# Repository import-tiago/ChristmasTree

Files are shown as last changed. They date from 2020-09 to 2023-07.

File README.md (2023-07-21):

# ChristmasTree

 

## PCB Preview
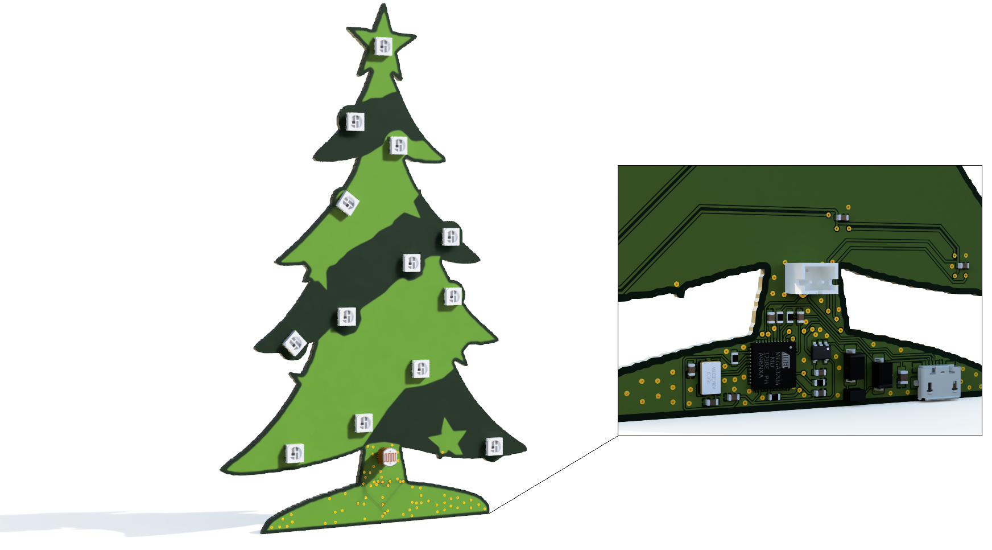
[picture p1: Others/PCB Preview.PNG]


## Schematic
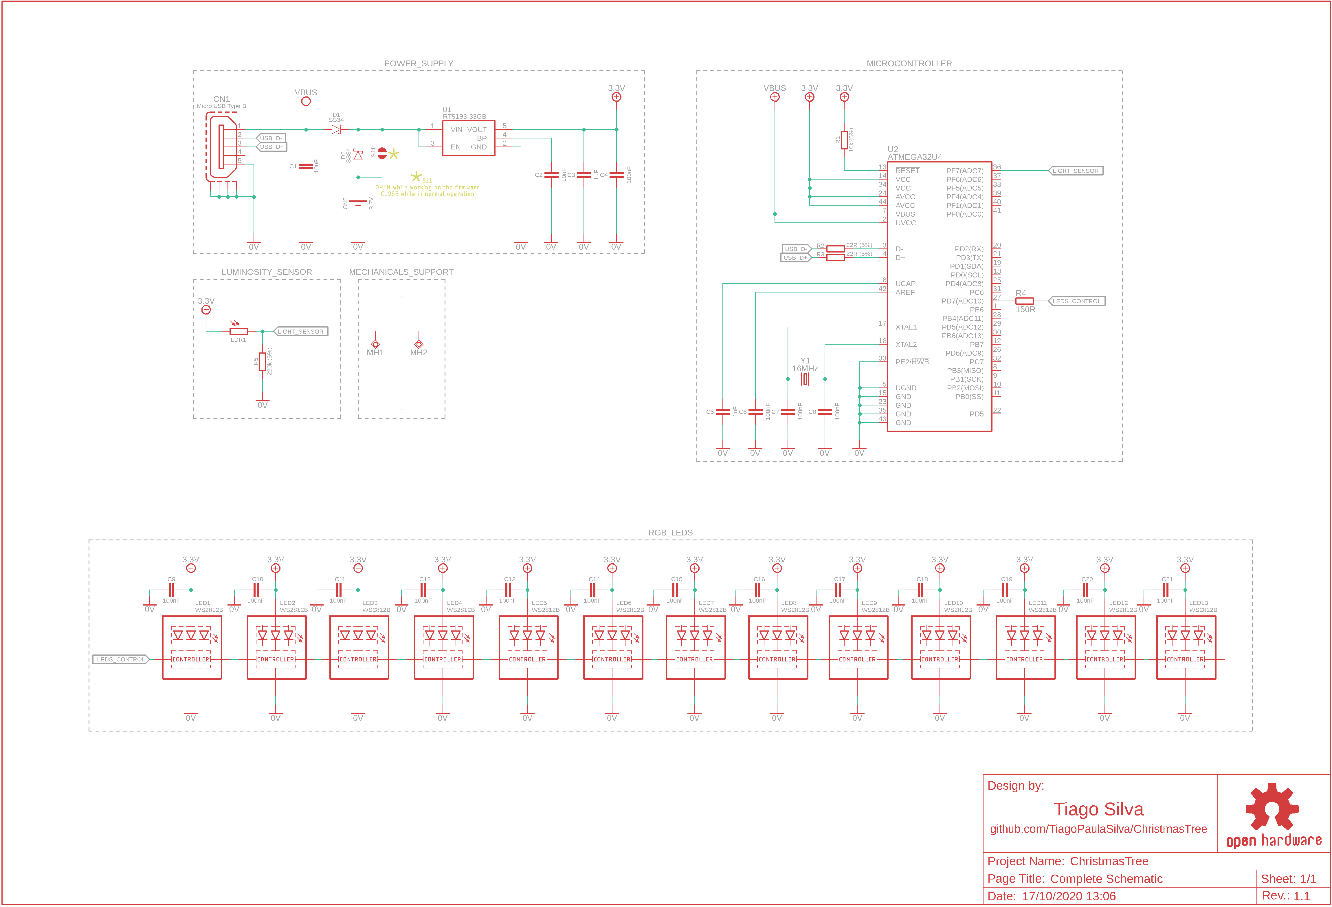
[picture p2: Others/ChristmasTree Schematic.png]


## Bill of Materials
| Qty | Parts | Description | Value | Package |
|--|--|--|--|--|
1|R1|SMD Resistor|10k ±5%|R0603
2|R2/R3|SMD Resistor|22R ±5%|R0603
1|R4|SMD Resistor|150R ±5%|R0603
1|R5|SMD Resistor|220k ±5%|R0603
1|C1|SMD Capacitor|1uF / 50V|C0805
1|C2|SMD Capacitor|10nF / 50V|C0603
2|C3/C5|SMD Capacitor|1uF / 50V|C0603
17|C4/C6~C21|SMD Capacitor|100nF / 50V|C0603
1|LDR1|PTH LDR|1 MΩ (Lux 0) / 10-20 KΩ (Lux 10)|5mm
1|Y1|SMD Crystal|8MHz|5.0mm x 3.2mm
1|U1|SMD Integrated Circuit|RT9193-33GB|SOT23-5
1|U2|SMD Integrated Circuit|ATMEGA32U4|QFN-44
2|D1/D2|SMD Diode|SS34|DO214AB
1|CN1|SMD Connector|MISB-SW-5B|Micro USB Type B
1|CN2|PTH Connector|JST-PH-2P|2-pin
13|LED1~LED13|SMD RGB LED|WS2812B|5050

### Contributing
0. Give this project a :star:
1. Create an issue and describe your idea.
2. [Fork it](https://github.com/import-tiago/ChristmasTree/fork).
3. Create your feature branch (`git checkout -b my-new-feature`).
4. Commit your changes (`git commit -a -m "Added feature title"`).
5. Publish the branch (`git push origin my-new-feature`).
6. Create a new pull request.
7. Done! :heavy_check_mark:

### License Information
<br /><span xmlns:dct="http://purl.org/dc/terms/" property="dct:title">ChristmasTree</span> by <a xmlns:cc="http://creativecommons.org/ns#" href="https://github.com/import-tiago" property="cc:attributionName" rel="cc:attributionURL">Tiago Silva</a> is licensed under a <a rel="license" href="http://creativecommons.org/licenses/by-sa/4.0/">Creative Commons Attribution-ShareAlike 4.0 International License</a>.<br />Permissions beyond the scope of this license may be available at <a xmlns:cc="http://creativecommons.org/ns#" href="https://twitter.com/import_tiago" rel="cc:morePermissions">tiagodepaulasilva@gmail.com</a>.

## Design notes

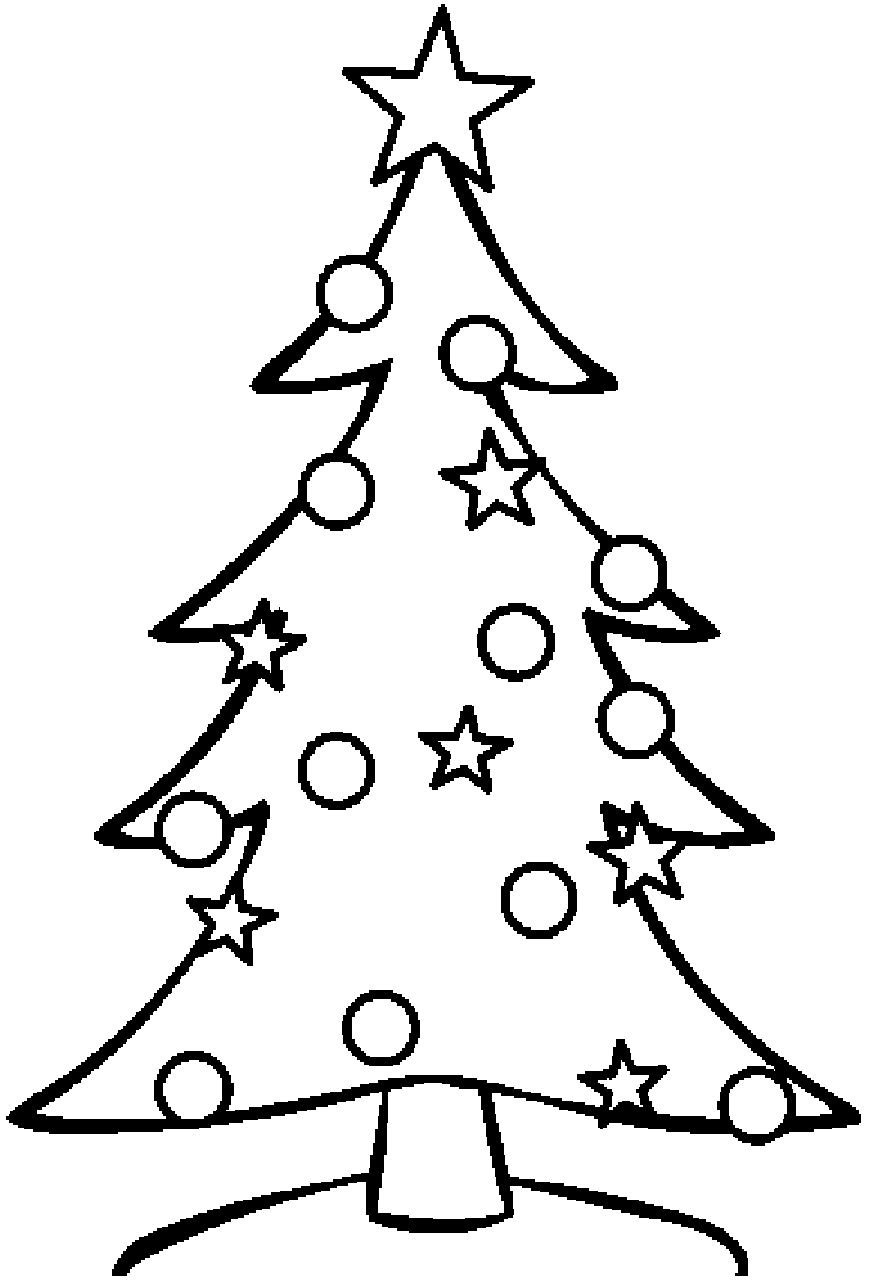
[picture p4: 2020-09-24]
Hardware/4. Others/ChristmasTree (Preview).bmp

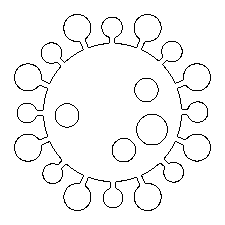
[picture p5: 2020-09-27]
Hardware/4. Others/Coronavirus.bmp

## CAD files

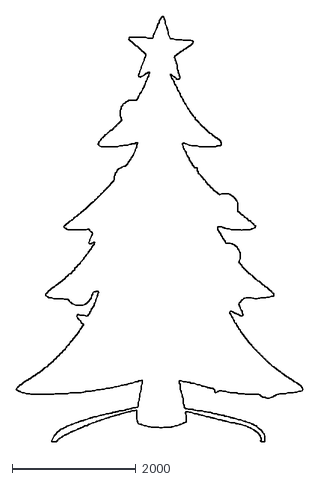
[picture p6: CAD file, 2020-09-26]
Hardware/4. Others/ChristmasTree (External Border).dxf
4616.3 x 6867.9

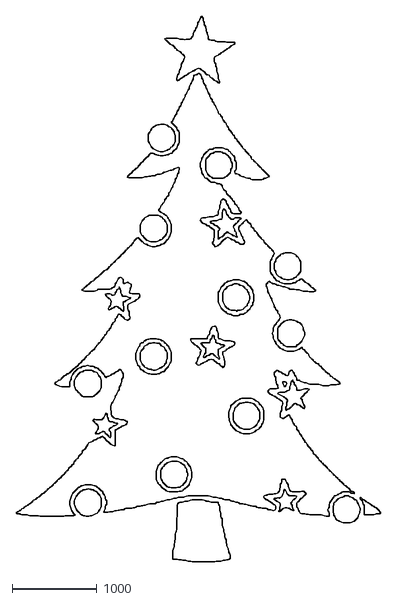
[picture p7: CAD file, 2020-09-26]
Hardware/4. Others/ChristmasTree (Internal Border).dxf
4292.5 x 6428.1

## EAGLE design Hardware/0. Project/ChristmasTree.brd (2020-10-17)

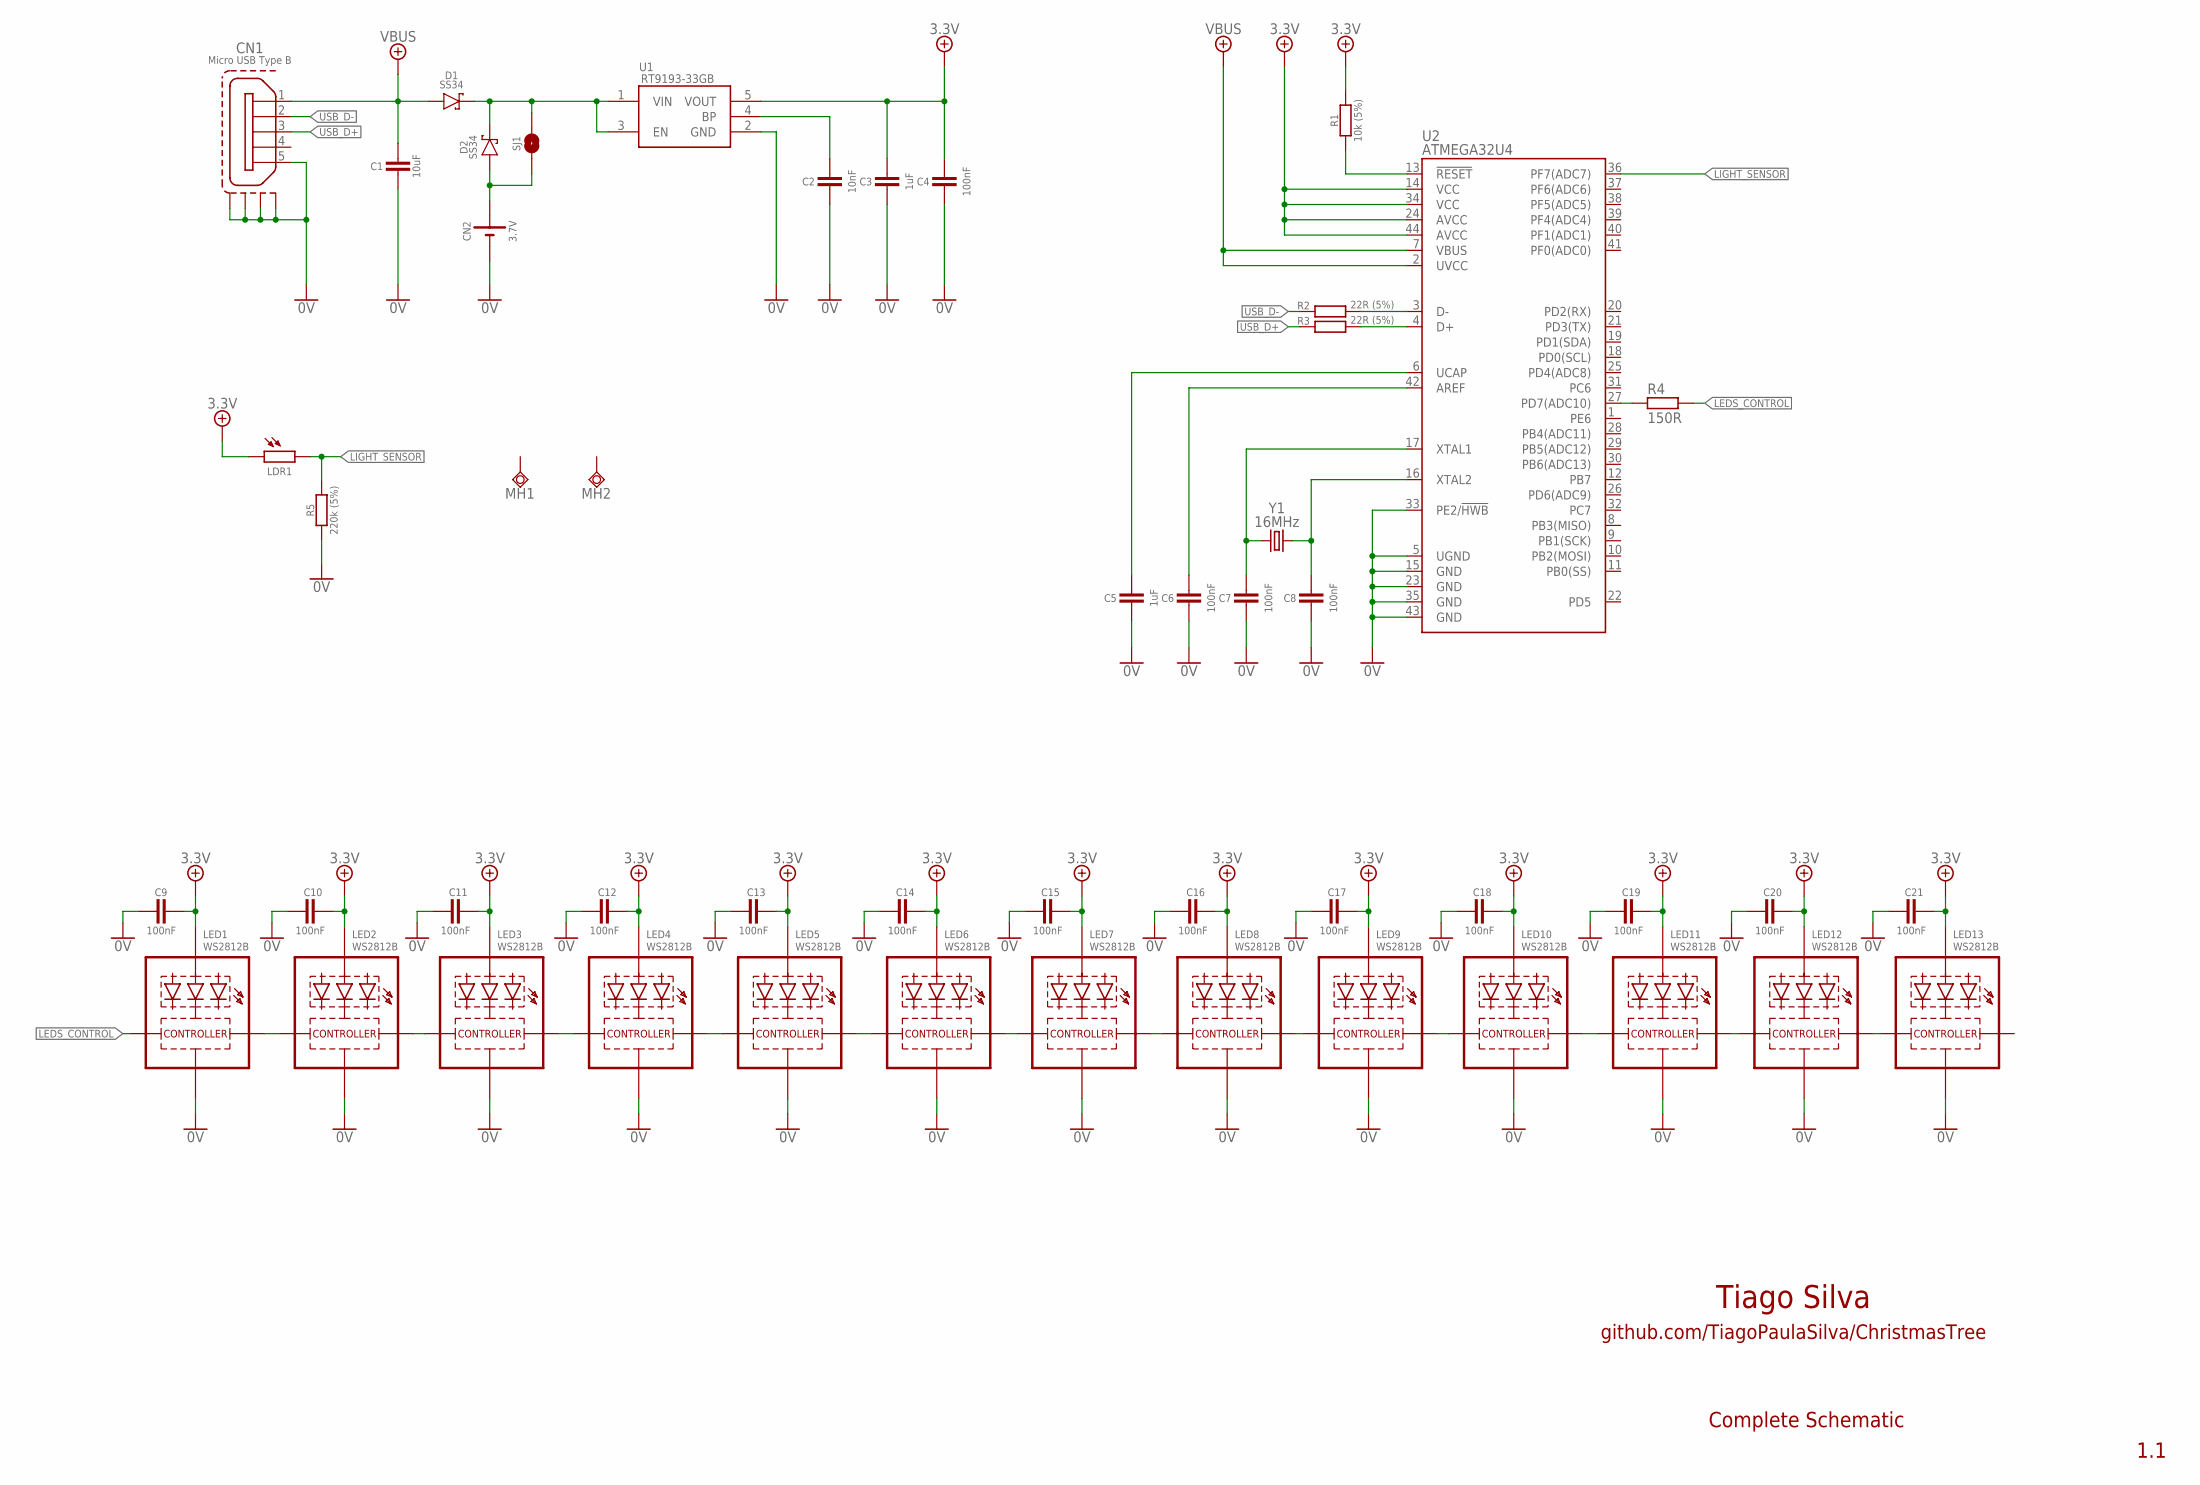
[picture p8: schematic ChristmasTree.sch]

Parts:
C1: 10uF; C0805
C2: 10nF; C0603
C3, C5: 1uF; C0603
C4, C6, C7, C8, C9, C10, C11, C12, C13, C14, C15, C16, C17, C18, C19, C20, C21: 100nF; C0603
CN1: Micro USB Type B; 10118193-0001LF
CN2: 3.7V; JST-PH2
D1, D2: SS34; DO214AB
LDR1: A1050_09; T0-46-A10XX
LED1, LED2, LED3, LED4, LED5, LED6, LED7, LED8, LED9, LED10, LED11, LED12, LED13: WS2812B; 5050
MH1, MH2: TPSQTP20R; TP20R
R1: 10k (5%); R0603
R2, R3: 22R (5%); R0603
R4: 150R; R0603
R5: 220k (5%); R0603
SJ1: SJ
U1: RT9193-33GB; SOT94P279X129-5N
U2: ATMEGA32U4; TESTING_QFN-44
Y1: 16MHz; 5.0X3.2_KX-9A

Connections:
0V: C1.2, C2.2, C3.2, C4.2, C5.2, C6.2, C7.2, C8.2, C9.2, C10.2, C11.2, C12.2, C13.2, C14.2, C15.2, C16.2, C17.2, C18.2, C19.2, C20.2, C21.2, CN1.5, CN1.MP1 (S1), CN1.MP2 (S2), CN1.MP3 (S3), CN1.MP4 (S4), CN2.2 (-), LED1.3-GND (GND), LED2.3-GND (GND), LED3.3-GND (GND), LED4.3-GND (GND), LED5.3-GND (GND), LED6.3-GND (GND), LED7.3-GND (GND), LED8.3-GND (GND), LED9.3-GND (GND), LED10.3-GND (GND), LED11.3-GND (GND), LED12.3-GND (GND), LED13.3-GND (GND), R5.1, U1.2 (GND), U2.5 (UGND), U2.15 (GND), U2.23 (GND), U2.33 (PE2/!HWB), U2.35 (GND), U2.43 (GND)
3.3V: C3.1, C4.1, C9.1, C10.1, C11.1, C12.1, C13.1, C14.1, C15.1, C16.1, C17.1, C18.1, C19.1, C20.1, C21.1, LDR1.1, LED1.1-VDD (VDD), LED2.1-VDD (VDD), LED3.1-VDD (VDD), LED4.1-VDD (VDD), LED5.1-VDD (VDD), LED6.1-VDD (VDD), LED7.1-VDD (VDD), LED8.1-VDD (VDD), LED9.1-VDD (VDD), LED10.1-VDD (VDD), LED11.1-VDD (VDD), LED12.1-VDD (VDD), LED13.1-VDD (VDD), R1.2, U1.5 (VOUT), U2.14 (VCC), U2.24 (AVCC), U2.34 (VCC), U2.44 (AVCC)
LEDS_CONTROL: LED1.4-DIN (DI), R4.2
LIGHT_SENSOR: LDR1.2, R5.2, U2.36 (PF7(ADC7))
unnamed: LED3.2-DOUT (DO), LED4.4-DIN (DI)
unnamed: LED1.2-DOUT (DO), LED2.4-DIN (DI)
unnamed: R4.1, U2.27 (PD7(ADC10))
unnamed: LED2.2-DOUT (DO), LED3.4-DIN (DI)
unnamed: LED5.2-DOUT (DO), LED6.4-DIN (DI)
unnamed: LED8.2-DOUT (DO), LED9.4-DIN (DI)
unnamed: LED6.2-DOUT (DO), LED7.4-DIN (DI)
unnamed: LED10.2-DOUT (DO), LED11.4-DIN (DI)
unnamed: LED9.2-DOUT (DO), LED10.4-DIN (DI)
unnamed: LED12.2-DOUT (DO), LED13.4-DIN (DI)
unnamed: LED4.2-DOUT (DO), LED5.4-DIN (DI)
unnamed: R3.2, U2.4 (D+)
unnamed: LED11.2-DOUT (DO), LED12.4-DIN (DI)
unnamed: LED7.2-DOUT (DO), LED8.4-DIN (DI)
unnamed: C7.1, U2.17 (XTAL1), Y1.1
unnamed: C8.1, U2.16 (XTAL2), Y1.3 (2)
unnamed: C5.1, U2.6 (UCAP)
unnamed: C6.1, U2.42 (AREF)
unnamed: CN2.1 (+), D2.A, SJ1.1
unnamed: R2.2, U2.3 (D-)
unnamed: C2.1, U1.4 (BP)
RESET: R1.1, U2.13 (!RESET)
USB_D+: CN1.3, R3.1
USB_D-: CN1.2, R2.1
VBAT: D1.C (K), D2.C (K), SJ1.2, U1.1 (VIN), U1.3 (EN)
VBUS: C1.1, CN1.1, D1.A, U2.2 (UVCC), U2.7 (VBUS)

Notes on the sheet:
Tiago Silva
github.com/TiagoPaulaSilva/ChristmasTree
1.1
Complete Schematic

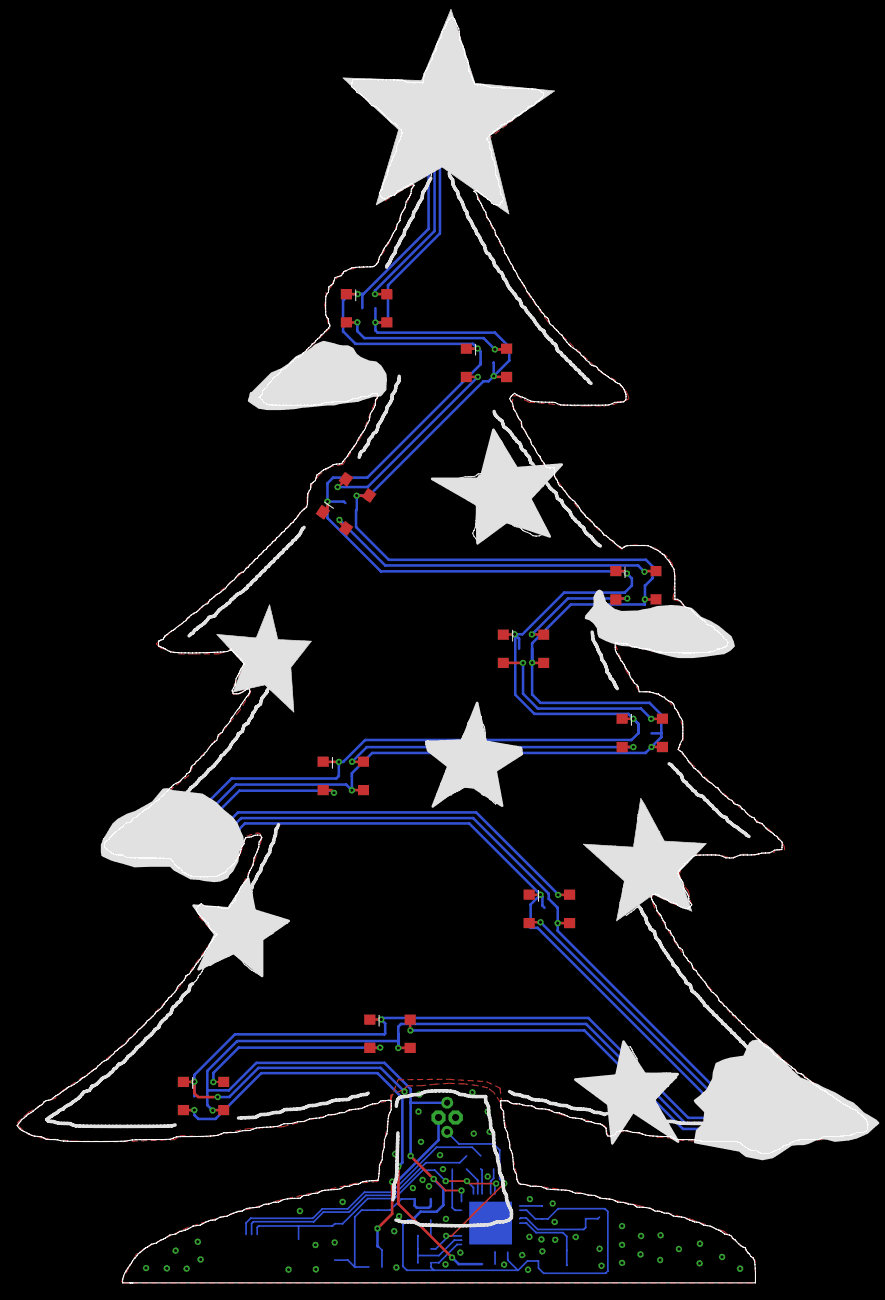
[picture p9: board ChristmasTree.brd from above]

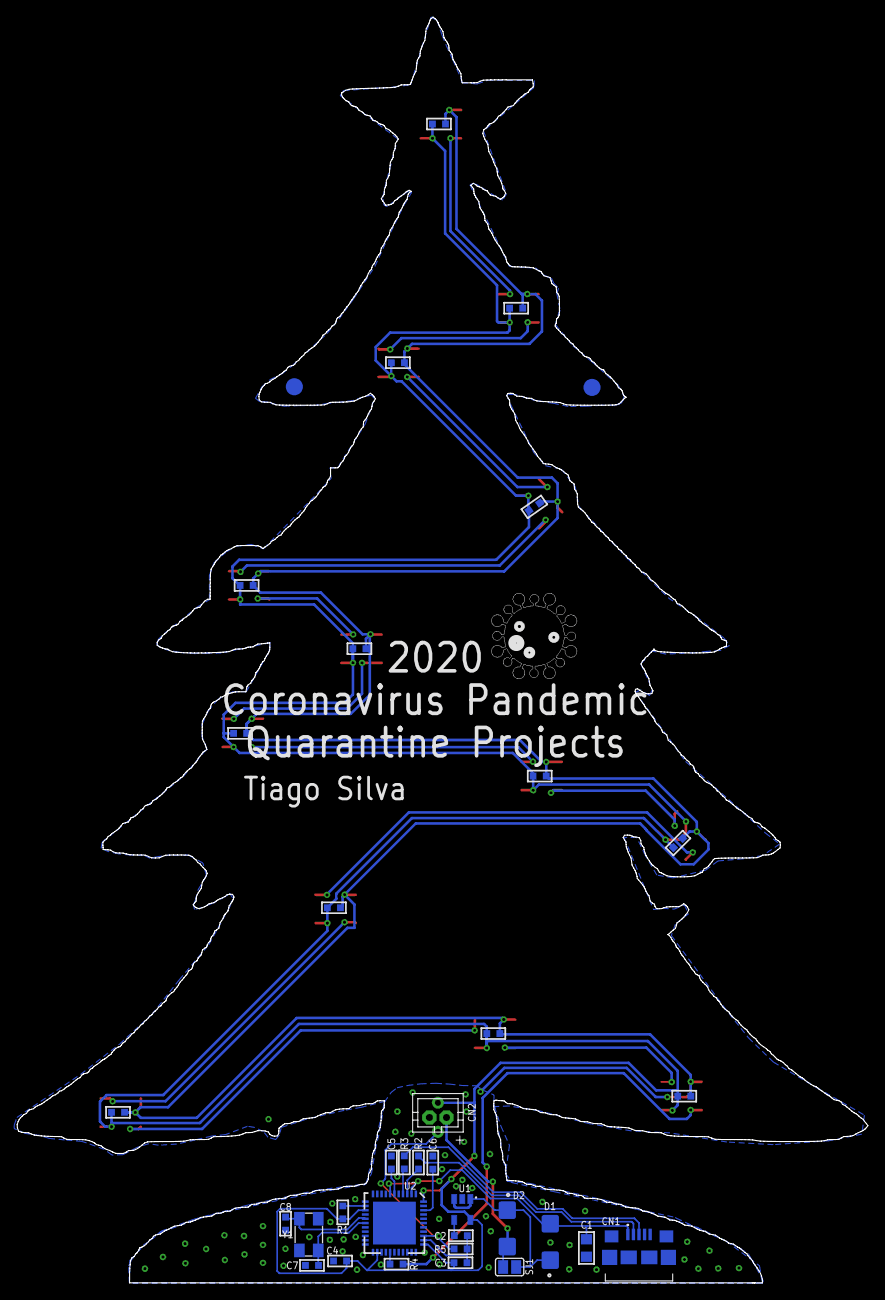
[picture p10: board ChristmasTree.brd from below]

Board: 2 copper layers, 99.3 x 147.7 mm, 50 parts (37 on the bottom side), 30 nets.

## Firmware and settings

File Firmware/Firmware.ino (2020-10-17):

/* sinelon

   By: Mark Kriegsman

   Modified by: Andrew Tuline

   Adapted by: Tiago Silva (2020)

   This uses the built in beat in FastLED to move a dot back and forth. In this case, it uses two beats added together for more randomness.

*/

#include "FastLED.h"                                          // FastLED library. Preferably the latest copy of FastLED 2.1.

#if FASTLED_VERSION < 3001000
#error "Requires FastLED 3.1 or later; check github for latest code."
#endif

#define NUM_LEDS 13
#define DATA_PIN 6

#define LDR_PIN A0
#define LIGHT_LEVEL 750

CRGB leds[NUM_LEDS];

// Global variables can be changed on the fly.
uint8_t max_bright = 64;                                      // Overall brightness definition. It can be changed on the fly.

CRGBPalette16 currentPalette;
CRGBPalette16 targetPalette;
TBlendType    currentBlending;                                // NOBLEND or LINEARBLEND

// Define variables used by the sequences.
uint8_t thisbeat =  23;                                       // Beats per minute for first part of dot.
uint8_t thatbeat =  28;                                       // Combined the above with this one.
uint8_t thisfade =   32;                                       // How quickly does it fade? Lower = slower fade rate.
uint8_t  thissat = 255;                                       // The saturation, where 255 = brilliant colours.
uint8_t  thisbri = 255;                                       // Brightness of a sequence.
int        myhue =   0;

int    thisdelay = 50;



void setup() {
  
  Serial.begin(9600);
  
  pinMode(LDR_PIN, INPUT);

  FastLED.addLeds<WS2812B, DATA_PIN, GRB>(leds, NUM_LEDS);

  currentBlending = LINEARBLEND;

  FastLED.setBrightness(max_bright);
  FastLED.setMaxPowerInVoltsAndMilliamps(3, 500);               // FastLED Power management set at 5V, 500mA.

} // setup()



void loop () {

  long Current_Light_Level = 0;
  for (int i = 0; i < 100; i++) {
    Current_Light_Level += analogRead(LDR_PIN);
  }
  Current_Light_Level /= 100;  
  Serial.println(Current_Light_Level);

  thisbri = Current_Light_Level / 4;

  if (thisbri < 30)
    thisbri = 30;

  //Serial.println(thisbri);
  if (Current_Light_Level < LIGHT_LEVEL) {

    EVERY_N_MILLISECONDS(50) {
      uint8_t maxChanges = 35;
      nblendPaletteTowardPalette(currentPalette, targetPalette, maxChanges);   // AWESOME palette blending capability.
    }

    EVERY_N_SECONDS(5) {                                        // Change the target palette to a random one every 5 seconds.
      static uint8_t baseC = random8();                         // You can use this as a baseline colour if you want similar hues in the next line.
      targetPalette = CRGBPalette16(CHSV(random8(), 255, random8(128, 255)), CHSV(random8(), 255, random8(128, 255)), CHSV(random8(), 192, random8(128, 255)), CHSV(random8(), 255, random8(128, 255)));
    }

    EVERY_N_MILLISECONDS(thisdelay) {                           // FastLED based non-blocking delay to update/display the sequence.
      sinelon();                                                // Call our sequence.
    }

    FastLED.show();
  }
  else {
    for (int i = 0; i < NUM_LEDS; i++) {
      leds[i] = CRGB::Black;
      FastLED.show();
    }
  }
}

void sinelon() {                                              // a colored dot sweeping back and forth, with fading trails

  fadeToBlackBy( leds, NUM_LEDS, thisfade);
  int pos1 = beatsin16(thisbeat, 0, NUM_LEDS);
  int pos2 = beatsin16(thatbeat, 0, NUM_LEDS);
  int pos = (pos1 + pos2) / 2;

  if (pos > (NUM_LEDS - 1))
    pos = 0;

  leds[pos] += ColorFromPalette(currentPalette, myhue++, thisbri, currentBlending);
}

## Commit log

2020-09-25 PCB 100mm
    [ChristmasTree.brd, ChristmasTree.sch]
2020-09-27 PCB 1.0 done
    [ChristmasTree (External Border).dxf, ChristmasTree (Internal Border).dxf, ChristmasTree.brd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]
2020-10-11 BoM added
2020-10-16 Basic firmware test
    [ChristmasTree.brd, ChristmasTree.sch]
2020-10-17 Light sensor code and LEDs effects working
2020-10-17 Adequacy of values in some components
    [ChristmasTree.brd, ChristmasTree.sch]
2020-10-17 Schematic preview updated to v1.1
2020-10-17 BOM updated to 1.1 schematic version

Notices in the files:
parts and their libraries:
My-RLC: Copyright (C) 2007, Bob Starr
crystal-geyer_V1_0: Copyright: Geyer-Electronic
